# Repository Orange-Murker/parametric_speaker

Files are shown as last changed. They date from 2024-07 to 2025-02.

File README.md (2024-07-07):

# Parametric Speaker

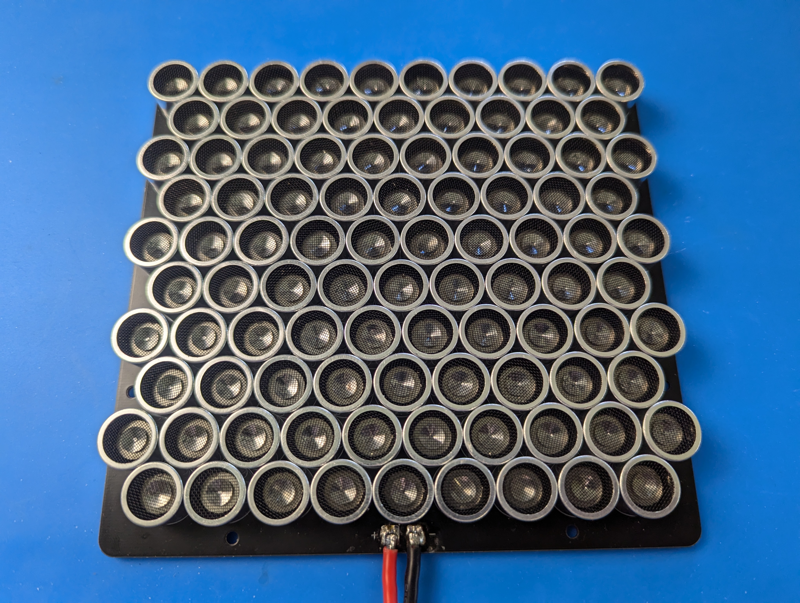
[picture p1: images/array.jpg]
Array


## What is this?

This is a directional speaker based on a parametric array of 95x 16mm 40kHz ultrasonic transducers.

The driver part of this design is currently only a working proof of concept and has some issues.
It consists of a single H-bridge directly driving the transducers with a 40kHz square wave without any additional filtering or matching.
The MOSFETs get really hot during the operation.

## Phase matching

Some transducers come with their polarity flipped even if they are from the same batch.
Thus it is important to match the phase of all of the transducers using the steps below:

1. Connect an oscilloscope to the receiver
2. Supply a 40kHz sine wave to the transducer
3. Physically align the transducer and the receiver in such a way that the wave supplied to the transducer has the same phase as the signal coming from the receiver
4. You now can mark the + and the - signs on this transducer-receiver pair and use it as the new reference.
5. Place a new transducer at the same distance from the receiver as the previous one and see if the phase is approximately the same between the two signals
6. If the phase does not match, flip the polarity of the transducer and it should now match
7. Insert the transducer into the PCB making sure that you insert it with the correct polarity according to the reference transducer polarity marked in step 4
8. Repeat steps 5-7 until you run out of transducers

## Additional Notes

The PCB assumes that the transducer bodies are electrically isolated from each
of the 2 pins. Not checking this may result in an unusable array due to a short.
Get transducers with a plastic housing if you want to avoid this.

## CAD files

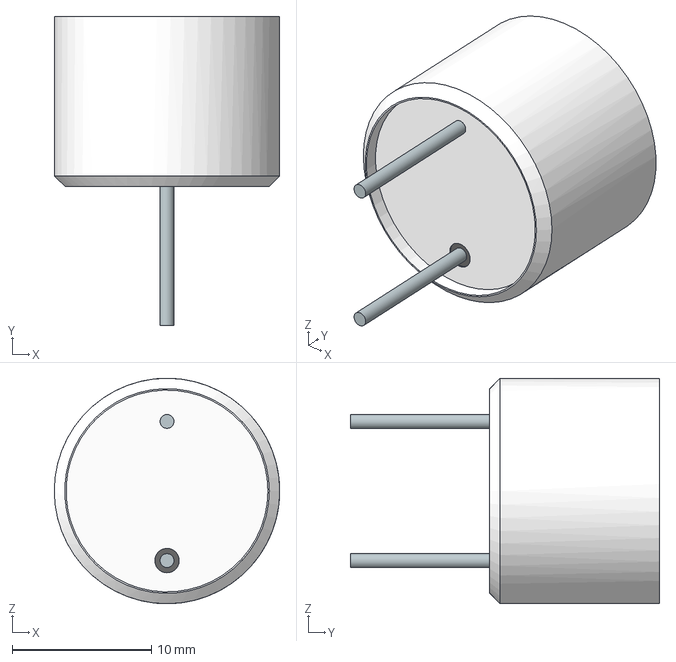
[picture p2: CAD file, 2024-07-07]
pcb/Models/transducer.step
16.2 x 22.2 x 16.2 mm

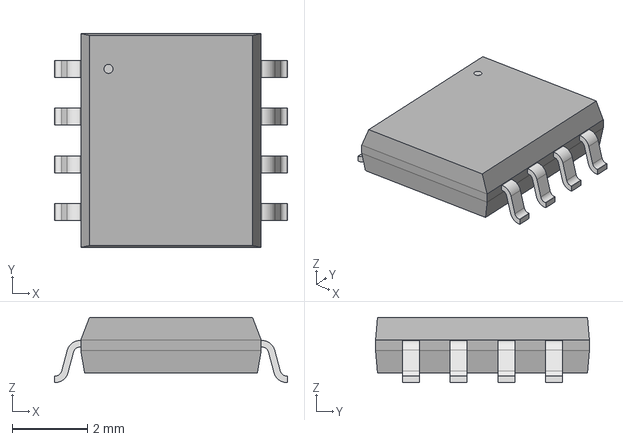
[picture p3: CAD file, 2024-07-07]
pcb/Models/PG-DSO-8-70.step
6.20 x 5.69 x 1.73 mm

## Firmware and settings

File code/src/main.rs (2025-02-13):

#![no_std]
#![no_main]

use defmt_rtt as _;
use panic_probe as _;

use stm32f4xx_hal as hal;

use core::cell::{OnceCell, RefCell};
use cortex_m::interrupt::Mutex;
use cortex_m_rt::entry;
use defmt::{error, info};
use fugit::{HertzU32, Rate};
use heapless::spsc::{self, Consumer, Producer};

use hal::{
    gpio::{Output, PushPull, PC13},
    interrupt,
    otg_fs::{UsbBus, USB},
    pac,
    pac::TIM1,
    prelude::*,
    timer::*,
};

use usb_device::{bus::UsbBusAllocator, prelude::*};
use usbd_audio::{AudioClass, AudioClassBuilder, StreamConfig, TerminalType};

const PWM_FREQ: HertzU32 = Rate::<u32, 1, 1>::kHz(40);
const AUDIO_QUEUE_SIZE: usize = 4096;
// The amount of samples with the value of 0 received before turning off the output
const NO_SIGNAL_SAMPLES: usize = 20000;

type PWMType = [ErasedChannel<TIM1>; 2];

static G_PWM_MANAGER: Mutex<RefCell<Option<PwmHzManager<TIM1>>>> = Mutex::new(RefCell::new(None));
static G_PWM_CHANNELS: Mutex<RefCell<Option<PWMType>>> = Mutex::new(RefCell::new(None));
static G_MAX_DUTY: Mutex<OnceCell<u16>> = Mutex::new(OnceCell::new());

static G_USB_AUDIO: Mutex<RefCell<Option<AudioClass<'static, UsbBus<USB>>>>> =
    Mutex::new(RefCell::new(None));
static G_USB_DEVICE: Mutex<RefCell<Option<UsbDevice<UsbBus<USB>>>>> =
    Mutex::new(RefCell::new(None));

static G_AUDIO_QUEUE_PROD: Mutex<RefCell<Option<Producer<'static, i16, AUDIO_QUEUE_SIZE>>>> =
    Mutex::new(RefCell::new(None));
static G_AUDIO_QUEUE_CONS: Mutex<RefCell<Option<Consumer<'static, i16, AUDIO_QUEUE_SIZE>>>> =
    Mutex::new(RefCell::new(None));

static LED: Mutex<RefCell<Option<PC13<Output<PushPull>>>>> = Mutex::new(RefCell::new(None));

fn set_output_state(pwm: &mut PWMType, enabled: bool) {
    // The output is disabled when the control signals are complementary
    // The primary output is ActiveHigh for C1 and ActiveLow for C2
    if enabled {
        pwm[0].set_complementary_polarity(Polarity::ActiveLow);
        pwm[1].set_complementary_polarity(Polarity::ActiveHigh);
    } else {
        pwm[0].set_complementary_polarity(Polarity::ActiveHigh);
        pwm[1].set_complementary_polarity(Polarity::ActiveLow);
    }
}

#[entry]
fn main() -> ! {
    static mut EP_MEMORY: [u32; 1024] = [0; 1024];
    static mut USB_BUS: Option<UsbBusAllocator<stm32f4xx_hal::otg_fs::UsbBusType>> = None;
    static mut AUDIO_QUEUE: spsc::Queue<i16, AUDIO_QUEUE_SIZE> = spsc::Queue::new();

    let mut c = cortex_m::Peripherals::take().unwrap();
    let p = pac::Peripherals::take().unwrap();

    let gpioa = p.GPIOA.split();
    let gpiob = p.GPIOB.split();
    let gpioc = p.GPIOC.split();

    let rcc = p.RCC.constrain();

    let clocks = rcc
        .cfgr
        .use_hse(25u32.MHz())
        .sysclk(96.MHz())
        .i2s_clk(61440.kHz())
        .require_pll48clk()
        .freeze();

    let led = gpioc.pc13.into_push_pull_output();

    cortex_m::interrupt::free(|cs| {
        LED.borrow(cs).replace(Some(led));
    });

    let (mut pwm_manager, (pwm_ch1, pwm_ch2, ..)) = p.TIM1.pwm_hz(PWM_FREQ, &clocks);
    let mut pwm_channels = [
        pwm_ch1
            .with(gpioa.pa8)
            .with_complementary(gpiob.pb13)
            .erase(),
        pwm_ch2
            .with(gpioa.pa9)
            .with_complementary(gpiob.pb14)
            .erase(),
    ];

    // Disable the output on power up
    set_output_state(&mut pwm_channels, false);

    pwm_channels[0].set_polarity(Polarity::ActiveHigh);
    pwm_channels[0].enable();
    pwm_channels[0].enable_complementary();

    pwm_channels[1].set_polarity(Polarity::ActiveLow);
    pwm_channels[1].enable();
    pwm_channels[1].enable_complementary();

    let max_duty = pwm_manager.get_max_duty();
    info!("Max duty: {}", max_duty);
    pwm_channels[0].set_duty(max_duty / 2);
    pwm_channels[1].set_duty(max_duty / 2);
    pwm_manager.listen(Event::C1);

    // Audio
    let (prod, cons) = AUDIO_QUEUE.split();

    let usb = USB::new(
        (p.OTG_FS_GLOBAL, p.OTG_FS_DEVICE, p.OTG_FS_PWRCLK),
        (gpioa.pa11, gpioa.pa12),
        &clocks,
    );

    *USB_BUS = Some(stm32f4xx_hal::otg_fs::UsbBusType::new(usb, EP_MEMORY));
    let usb_bus = USB_BUS.as_ref().unwrap();

    cortex_m::interrupt::free(|cs| {
        G_AUDIO_QUEUE_PROD.borrow(cs).replace(Some(prod));
        G_AUDIO_QUEUE_CONS.borrow(cs).replace(Some(cons));

        G_USB_AUDIO.borrow(cs).replace(Some(
            AudioClassBuilder::new()
                .output(
                    StreamConfig::new_discrete(
                        usbd_audio::Format::S16le,
                        1,
                        &[40000],
                        TerminalType::OutSpeaker,
                    )
                    .unwrap(),
                )
                .build(usb_bus)
                .unwrap(),
        ));

        G_USB_DEVICE.borrow(cs).replace(Some(
            UsbDeviceBuilder::new(usb_bus, UsbVidPid(0x16c0, 0x27e0))
                .max_packet_size_0(64).unwrap()
                .strings(&[StringDescriptors::default()
                    .manufacturer("Orange_Murker")
                    .product("Parametric Speaker")])
                .unwrap()
                .build(),
        ));
    });

    cortex_m::interrupt::free(|cs| {
        G_PWM_MANAGER.borrow(cs).replace(Some(pwm_manager));
        G_PWM_CHANNELS.borrow(cs).replace(Some(pwm_channels));
        G_MAX_DUTY.borrow(cs).get_or_init(|| max_duty);
    });

    unsafe {
        c.NVIC.set_priority(pac::Interrupt::OTG_FS, 16);

        cortex_m::peripheral::NVIC::unmask(pac::Interrupt::TIM1_CC);
        cortex_m::peripheral::NVIC::unmask(pac::Interrupt::OTG_FS);
    }
    info!(
        "OTG interrupt priority: {}",
        cortex_m::peripheral::NVIC::get_priority(pac::Interrupt::OTG_FS)
    );

    loop {}
}

#[interrupt]
fn TIM1_CC() {
    static mut PWM_MANAGER: Option<PwmHzManager<TIM1>> = None;
    static mut PWM_CHANNELS: Option<PWMType> = None;
    static mut MAX_DUTY: Option<u16> = None;
    static mut AUDIO_QUEUE_CONS: Option<Consumer<'static, i16, AUDIO_QUEUE_SIZE>> = None;
    // Disable the output at the start
    static mut ZERO_COUNT: usize = NO_SIGNAL_SAMPLES + 1;

    let pwm_manager = PWM_MANAGER.get_or_insert_with(|| {
        cortex_m::interrupt::free(|cs| G_PWM_MANAGER.borrow(cs).take().unwrap())
    });
    let pwm_channels = PWM_CHANNELS.get_or_insert_with(|| {
        cortex_m::interrupt::free(|cs| G_PWM_CHANNELS.borrow(cs).take().unwrap())
    });
    let max_duty = MAX_DUTY.get_or_insert_with(|| {
        cortex_m::interrupt::free(|cs| *G_MAX_DUTY.borrow(cs).get().unwrap())
    });
    let queue = AUDIO_QUEUE_CONS.get_or_insert_with(|| {
        cortex_m::interrupt::free(|cs| G_AUDIO_QUEUE_CONS.borrow(cs).take().unwrap())
    });

    pwm_manager.clear_flags(Flag::C1);

    // cortex_m::interrupt::free(|cs| {
    //     let mut led = LED.borrow(cs).take().unwrap();
    //     led.set_high();
    //     LED.borrow(cs).replace(Some(led));
    // });

    const AMPLIFY: i32 = 0000;

    let min = i16::MIN as i32 + AMPLIFY;
    let max = i16::MAX as i32 - AMPLIFY;

    let value = if let Some(value) = queue.dequeue() {
        value
    } else {
        error!("Underrun");
        0
    };

    if value == 0 {
        *ZERO_COUNT = ZERO_COUNT.saturating_add(1);
        // Disable the output when there is no signal
        if *ZERO_COUNT > NO_SIGNAL_SAMPLES {
            set_output_state(pwm_channels, false);
        }
    } else {
        // Re-enable the output
        set_output_state(pwm_channels, true);
        *ZERO_COUNT = 0;
    }

    let duty = ((*max_duty as i32 * (value as i32 - min)) / (max - min)) as u16;

    // info!("Duty: {}", duty);

    pwm_channels[0].set_duty(duty as u16);
    pwm_channels[1].set_duty(duty as u16);

    // cortex_m::interrupt::free(|cs| {
    //     let mut led = LED.borrow(cs).take().unwrap();
    //     led.set_low();
    //     LED.borrow(cs).replace(Some(led));
    // });
}

#[interrupt]
fn OTG_FS() {
    static mut USB_DEVICE: Option<UsbDevice<UsbBus<USB>>> = None;
    static mut USB_AUDIO: Option<AudioClass<'static, UsbBus<USB>>> = None;
    static mut AUDIO_QUEUE_PROD: Option<Producer<'static, i16, AUDIO_QUEUE_SIZE>> = None;

    let usb_audio = USB_AUDIO.get_or_insert_with(|| {
        cortex_m::interrupt::free(|cs| G_USB_AUDIO.borrow(cs).take().unwrap())
    });

    let usb_dev = USB_DEVICE.get_or_insert_with(|| {
        cortex_m::interrupt::free(|cs| G_USB_DEVICE.borrow(cs).take().unwrap())
    });

    let queue = AUDIO_QUEUE_PROD.get_or_insert_with(|| {
        cortex_m::interrupt::free(|cs| G_AUDIO_QUEUE_PROD.borrow(cs).take().unwrap())
    });

    if usb_dev.poll(&mut [usb_audio]) {
        let mut buf: [u8; 1024] = [0u8; 1024];
        if let Ok(len) = usb_audio.read(&mut buf) {
            let data = &buf[0..len];
            // info!("{}", len);
            for x in data.chunks_exact(2) {
                let val = i16::from_le_bytes(
                    x.try_into()
                        .expect("Should not panic because chunks are always 2 bytes"),
                );
                // info!("Val: {}", val);
                if queue.enqueue(val).is_err() {
                    error!("Overrun");
                }
            }
        }
    }
}
